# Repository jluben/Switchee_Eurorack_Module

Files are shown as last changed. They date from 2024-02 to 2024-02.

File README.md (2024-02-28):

# Switchee Eurorack Module
Switchee is a Eurorack signal switcher using the ATSAMD10D14A. It's a fairly simple design that uses the MCU to control DG447 analog signal switchers. The DG447 a cheap and can handle the full voltage bandwidth of typical Eurorack signals. Assemble is with SMD components, and the PCB falls into budget range of JLCPCB. When this was designed in 2022, you could build a unit for under $30. Even cheaper if you wanted to build ten units.

The default behavior is to advance the output from one to four for each trigger input. The mode button changes this behavior. There are three counting modes: linear, exponential (up to 1024), and fibonacci. In exponential mode, it takes an increase number of triggers to advance the counter and change the output. For example, 2, 4, 8, 16, etc. The fibonacci mode is similiar: it takes 1, 1, 2, 3, 5, 8 and so on triggers to change the output routing.

The module has:
* A TRIGGER input that changes the output
* A Signal input that is buffered and routed to one of four outputs
* A Reset input that changes the switching back to Output One
* A Mode button 

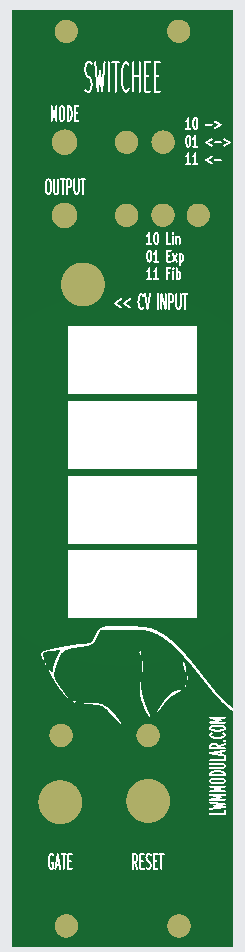
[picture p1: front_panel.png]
Front Panel Preview

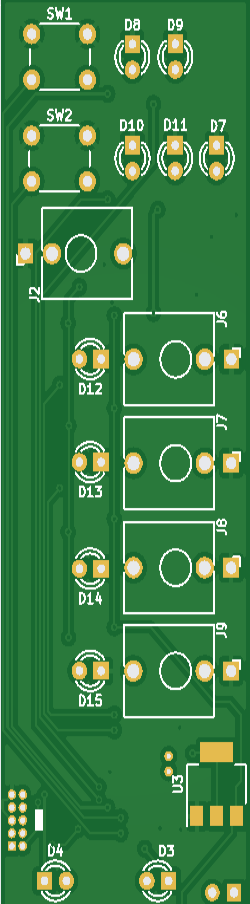
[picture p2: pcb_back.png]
PCB Back

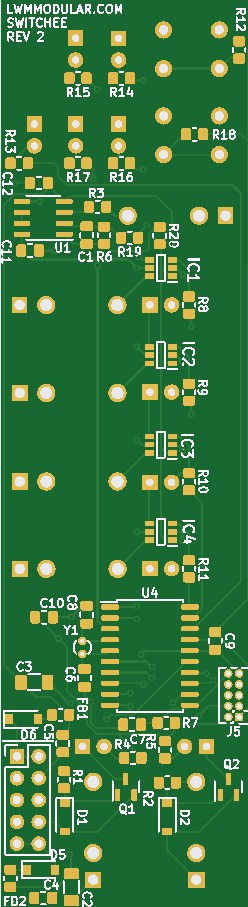
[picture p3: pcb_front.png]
PCB Front


This project includes the PCB, PCB front panel, and firmware. Firmware is downloaded to the ATSAMD10 via ATMEL ICE.

The PCB is done in Kicad. There are fab-ready gerbers in the gerbers/ directory. The main firmware file is in firmware/main.c

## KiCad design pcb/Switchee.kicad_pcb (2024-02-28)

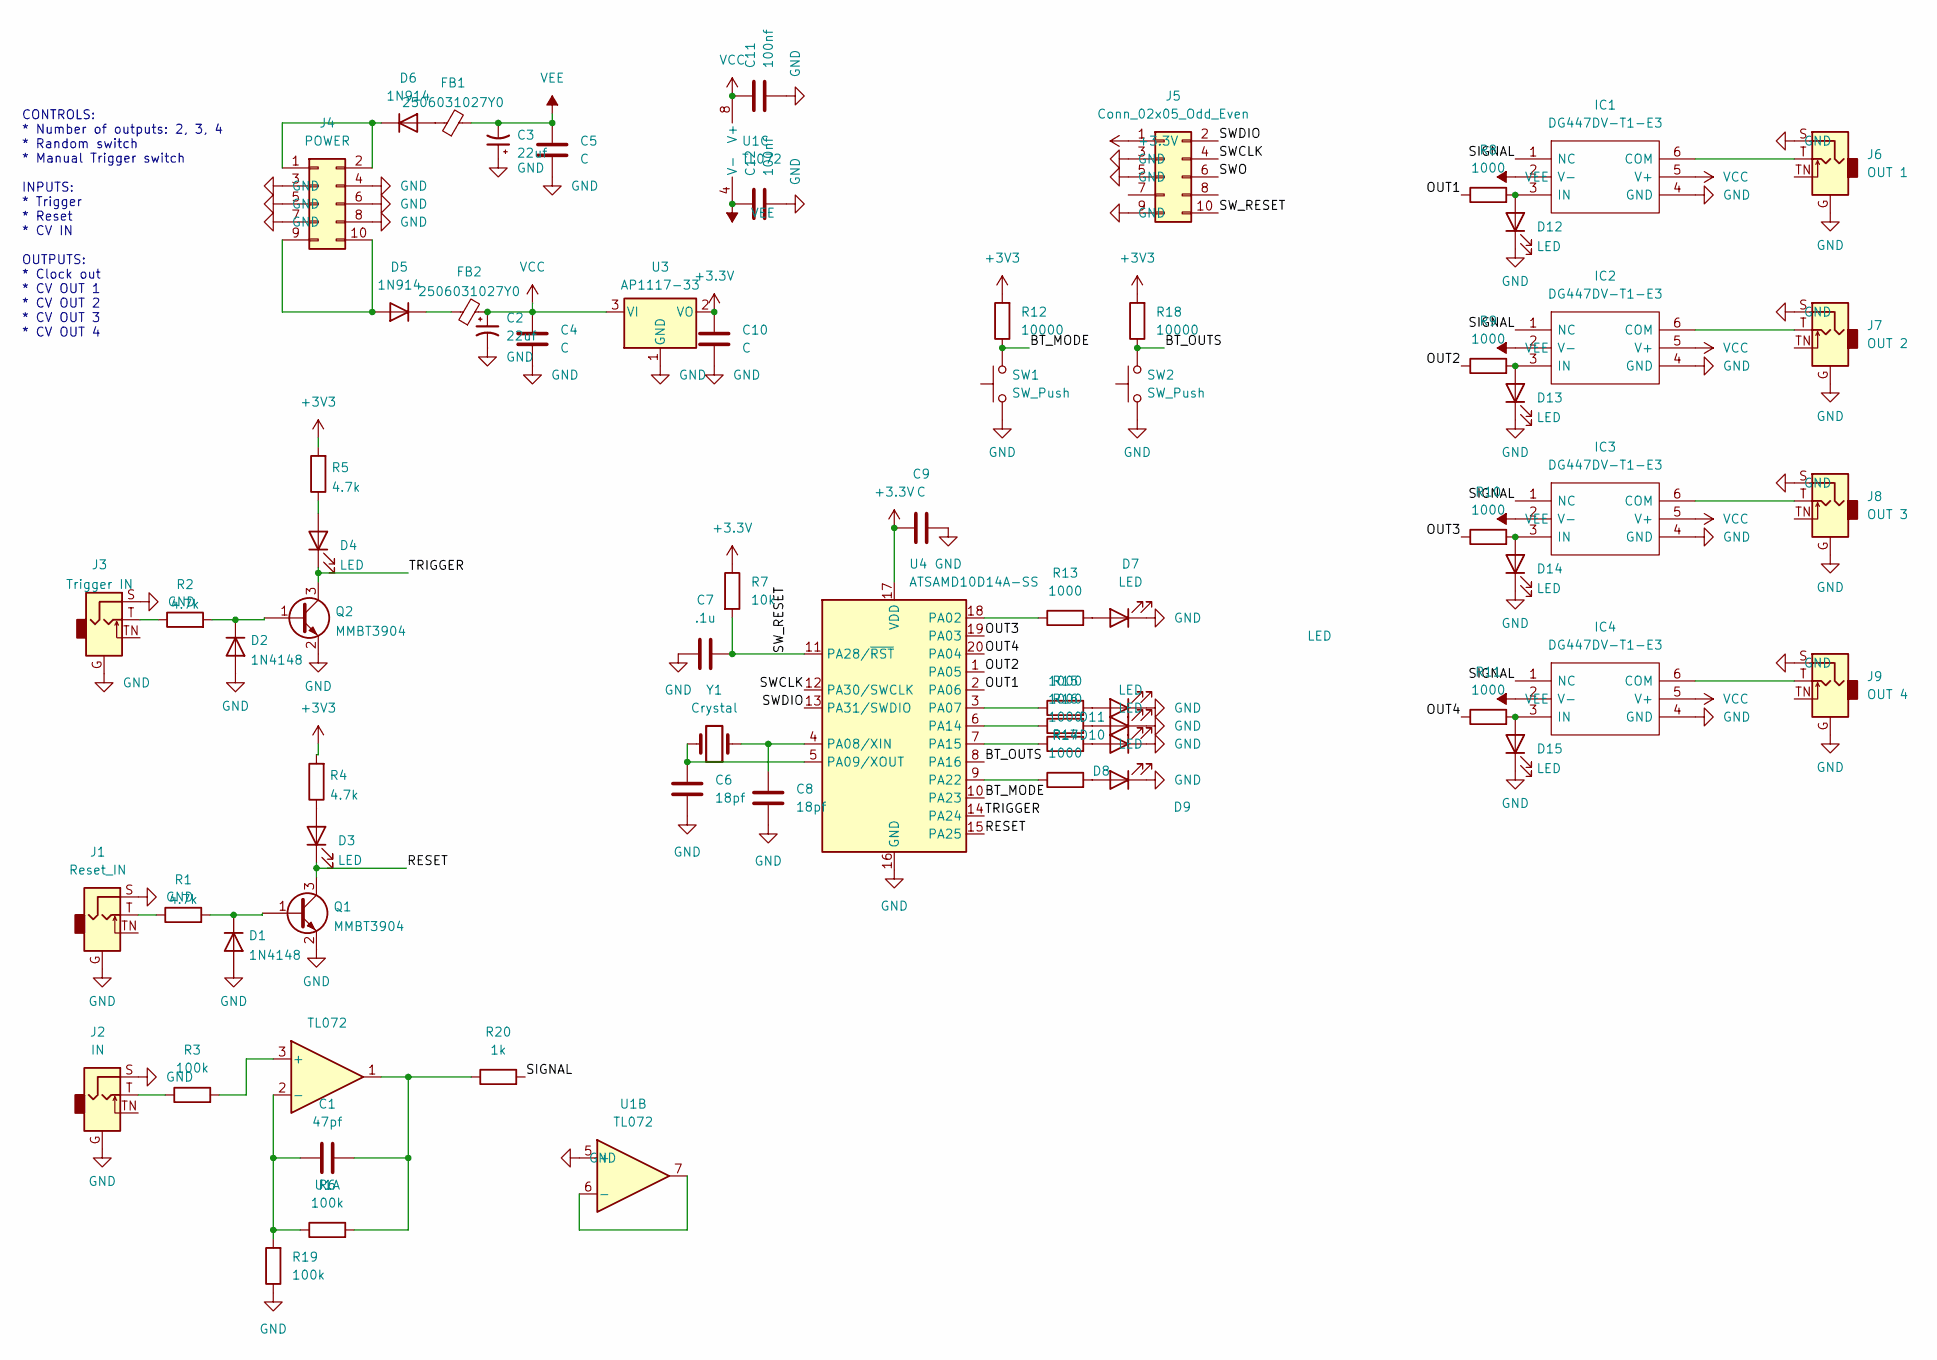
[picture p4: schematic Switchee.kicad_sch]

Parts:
C1: 47pf; C_0805_2012Metric_Pad1.18x1.45mm_HandSolder
C2, C3: 22uf; C_1206_3216Metric_Pad1.33x1.80mm_HandSolder
C4, C5, C9, C10: C; C_0805_2012Metric_Pad1.18x1.45mm_HandSolder
C6, C8: 18pf; C_0805_2012Metric_Pad1.18x1.45mm_HandSolder
C7: .1u; C_0805_2012Metric_Pad1.18x1.45mm_HandSolder
C11, C12: 100nf; C_0805_2012Metric_Pad1.18x1.45mm_HandSolder
D1, D2: 1N4148; D_SOD-123
D3, D4, D7, D8, D9, D10, D11, D12, D13, D14, D15: LED; LED_D3.0mm
D5, D6: 1N914; D_SOD-123
FB1, FB2: 2506031027Y0; R_0805_2012Metric_Pad1.20x1.40mm_HandSolder
IC1, IC2, IC3, IC4: DG447DV-T1-E3; SOP95P284X110-6N; Mouser Part Number 781-DG447DV-E3
J1: Reset_IN; Jack_3.5mm_QingPu_WQP-PJ398SM_Vertical_CircularHoles
J2: IN; Jack_3.5mm_QingPu_WQP-PJ398SM_Vertical_CircularHoles
J3: Trigger IN; Jack_3.5mm_QingPu_WQP-PJ398SM_Vertical_CircularHoles
J4: POWER; PinHeader_2x05_P2.54mm_Vertical
J5: Conn_02x05_Odd_Even; PinHeader_2x05_P1.27mm_Vertical
J6: OUT 1; Jack_3.5mm_QingPu_WQP-PJ398SM_Vertical_CircularHoles
J7: OUT 2; Jack_3.5mm_QingPu_WQP-PJ398SM_Vertical_CircularHoles
J8: OUT 3; Jack_3.5mm_QingPu_WQP-PJ398SM_Vertical_CircularHoles
J9: OUT 4; Jack_3.5mm_QingPu_WQP-PJ398SM_Vertical_CircularHoles
Q1, Q2: MMBT3904; SOT-23
R1, R2, R4, R5: 4.7k; R_0805_2012Metric_Pad1.20x1.40mm_HandSolder
R3, R6, R19: 100k; R_0805_2012Metric_Pad1.20x1.40mm_HandSolder
R7: 10k; R_0805_2012Metric_Pad1.20x1.40mm_HandSolder
R8, R9, R10, R11, R13, R14, R15, R16, R17: 1000; R_0805_2012Metric_Pad1.20x1.40mm_HandSolder
R12, R18: 10000; R_0805_2012Metric_Pad1.20x1.40mm_HandSolder
R20: 1k; R_0805_2012Metric_Pad1.20x1.40mm_HandSolder
SW1, SW2: SW_Push; SW_PUSH_6mm
U1: TL072; SOIC-8_3.9x4.9mm_P1.27mm
U3: AP1117-33; SOT-223-3_TabPin2
U4: ATSAMD10D14A-SS; SOIC-20W_7.5x12.8mm_P1.27mm
Y1: Crystal; Crystal_Round_D1.0mm_Vertical

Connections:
/BT_MODE: R12.1, SW1.2, U4.10 (PA23)
/BT_OUTS: R18.1, SW2.2, U4.8 (PA16)
/OUT1: R8.1, U4.2 (PA06)
/OUT2: R9.1, U4.1 (PA05)
/OUT3: R10.1, U4.19 (PA03)
/OUT4: R11.1, U4.20 (PA04)
/RESET: D3.1 (K), Q1.3 (C), U4.15 (PA25)
/SIGNAL: IC1.1 (NC), IC2.1 (NC), IC3.1 (NC), IC4.1 (NC), R20.2
/SWCLK: J5.4, U4.12 (PA30/SWCLK)
/SWDIO: J5.2, U4.13 (PA31/SWDIO)
/SWO: J5.6
/SW_RESET: C7.1, J5.10, R7.2, U4.11 (PA28/~RST)
/TRIGGER: D4.1 (K), Q2.3 (C), U4.14 (PA24)
GND: C2.2, C3.1, C4.2, C5.2, C6.2, C7.2, C8.2, C9.2, C10.2, C11.2, C12.2, D1.2 (A), D2.2 (A), D7.1 (K), D8.1 (K), D9.1 (K), D10.1 (K), D11.1 (K), D12.1 (K), D13.1 (K), D14.1 (K), D15.1 (K), IC1.4 (GND), IC2.4 (GND), IC3.4 (GND), IC4.4 (GND), J1.G, J1.S, J2.G, J2.S, J3.G, J3.S, J4.3, J4.4, J4.5, J4.6, J4.7, J4.8, J5.3, J5.5, J5.9, J6.G, J6.S, J7.G, J7.S, J8.G, J8.S, J9.G, J9.S, Q1.2 (E), Q2.2 (E), R19.1, SW1.1, SW2.1, U1.5 (+), U3.1 (GND), U4.16 (GND)
unnamed: C1.2, R6.2, R20.1, U1.1
unnamed: C6.1, U4.5 (PA09/XOUT), Y1.2
unnamed: C8.1, U4.4 (PA08/XIN), Y1.1
unnamed: D1.1 (K), Q1.1 (B), R1.2
unnamed: D2.1 (K), Q2.1 (B), R2.2
unnamed: D3.2 (A), R4.1
unnamed: D4.2 (A), R5.1
unnamed: D5.1 (K), FB2.1
unnamed: D5.2 (A), J4.9, J4.10
unnamed: D6.1 (K), J4.1, J4.2
unnamed: D6.2 (A), FB1.1
unnamed: D7.2 (A), R13.2
unnamed: D8.2 (A), R14.2
unnamed: D9.2 (A), R15.2
unnamed: D10.2 (A), R16.2
unnamed: D11.2 (A), R17.2
unnamed: D12.2 (A), IC1.3 (IN), R8.2
unnamed: D13.2 (A), IC2.3 (IN), R9.2
unnamed: D14.2 (A), IC3.3 (IN), R10.2
unnamed: D15.2 (A), IC4.3 (IN), R11.2
unnamed: IC1.6 (COM), J6.T
unnamed: IC2.6 (COM), J7.T
unnamed: IC3.6 (COM), J8.T
unnamed: IC4.6 (COM), J9.T
unnamed: J1.T, R1.1
unnamed: J2.T, R3.1
unnamed: J3.T, R2.1
unnamed: R3.2, U1.3 (+)
unnamed: R13.1, U4.18 (PA02)
unnamed: R14.1, U4.9 (PA22)
unnamed: R15.1, U4.6 (PA14)
unnamed: R16.1, U4.7 (PA15)
unnamed: R17.1, U4.3 (PA07)
unnamed: C1.1, R6.1, R19.2, U1.2 (-)
unnamed: U1.6 (-), U1.7
VCC: C2.1, C4.1, C11.1, FB2.2, IC1.5 (V+), IC2.5 (V+), IC3.5 (V+), IC4.5 (V+), U1.8 (V+), U3.3 (VI)
VEE: C3.2, C5.1, C12.1, FB1.2, IC1.2 (V-), IC2.2 (V-), IC3.2 (V-), IC4.2 (V-), U1.4 (V-)

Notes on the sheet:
CONTROLS: * Number of outputs: 2, 3, 4 * Random switch * Manual Trigger switch INPUTS: * Trigger * Reset * CV IN OUTPUTS: * Clock out * CV OUT 1 * CV OUT 2 * CV OUT 3 * CV OUT 4

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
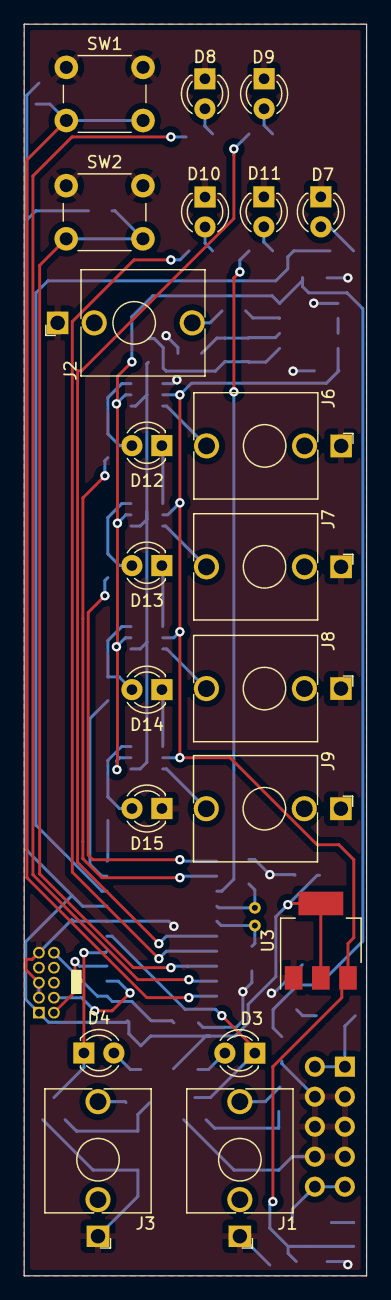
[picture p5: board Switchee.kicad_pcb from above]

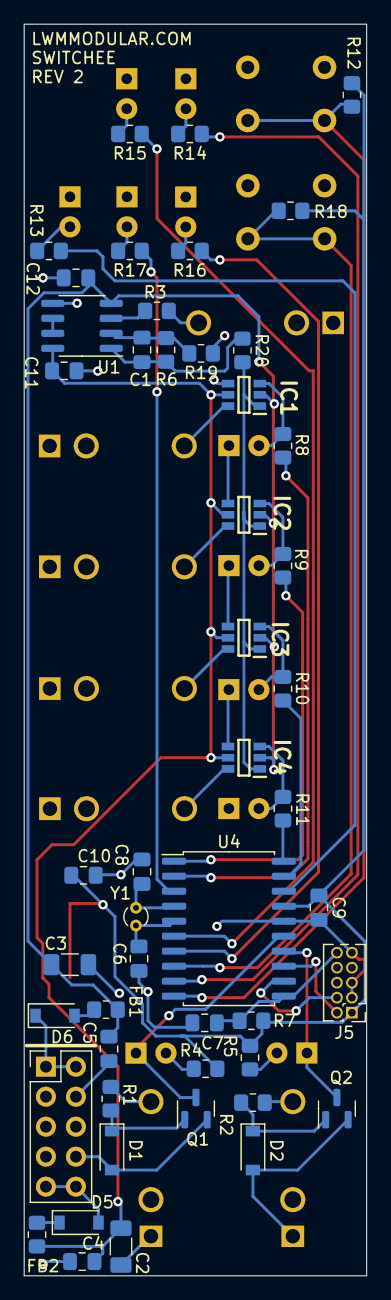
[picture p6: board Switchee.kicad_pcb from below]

Board: 2 copper layers, 29.0 x 106.0 mm, 70 parts (49 on the bottom side), 51 nets.

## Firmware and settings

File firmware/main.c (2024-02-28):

/**
 * This is the firmware for the Switchee Eurorack module. It is designed around a ATSAMD10. The 
 * MCU looks for trigger and reset inputs, and then decides how to change the output routing of 
 * the four analog signal switchers (DG447). A lot of this code is management of the hardware
 * user interface. The mode is saved to flash after a long enough delay to not exceed the flash
 * lifetime.
*/
#include <atmel_start.h>

enum 
{
	kModeSequential=0,
	kModeBounce=1,
	kModeInverted=2,
	
	kModeLast
};

enum
{
	kCounterModeLinear=0,
	kCounterModeExponential,
	kCounterModeFibonacci,
	
	kCounterModeLast
};

typedef enum
{
	kForwards,
	kBackwards
	
} BounceDirection;
	
const int kLongHoldTicks = 20000;
const int kSaveSettingsDelay = 500000;
const int kDebounceTicks = 1000;
const int kDebounceSignalTicks = 1000;
#define kExponentialSize  10
const int32_t kExponential[kExponentialSize] = {2, 4, 8, 16, 32, 64, 128, 256, 512, 1024};
#define kFibonacciSize  18
const int32_t kFibonacci[kFibonacciSize] = {0, 1, 1, 2, 3, 5, 8, 13, 21, 34, 55, 89, 144, 233, 377, 610, 987, 1597};

volatile int64_t gTicks=0;
volatile int8_t gChannel1=false;
volatile int8_t gChannel2=false;
volatile int8_t gChannel3=false;
volatile int8_t gChannel4=false;
volatile int8_t gLinearChannelIndex=0;
volatile BounceDirection gBounceDirection=kForwards;
volatile bool gSettingsDirty=false;
volatile bool gInvertChannels=false;
volatile int32_t gCounter=0;


volatile int8_t gSwitcheeMode=kModeSequential;
volatile int8_t gCounterMode=kCounterModeLinear;

static void TIMER_0_task1_cb(const struct timer_task *const timer_task)
{
	++gTicks;
}

static struct timer_task TIMER_0_task1;
void setupTimer(void)
{
	TIMER_0_task1.interval = 2;
	TIMER_0_task1.cb       = TIMER_0_task1_cb;
	TIMER_0_task1.mode     = TIMER_TASK_REPEAT;

	timer_add_task(&TIMER_0, &TIMER_0_task1);
	timer_start(&TIMER_0);
}


void setCounterModeIndicators()
{
	bool D10=false;
	bool D11=false;
	
	switch (gCounterMode)
	{
		case kCounterModeLinear:
			D10 = true;
			break;
		case kCounterModeExponential:
			D11 = true;
			break;
		case kModeInverted:
			D10 = true;
			D11 = true;
			break;
	}
	
	gpio_set_pin_level(LED10, D10);
	gpio_set_pin_level(LED11, D11);
}


void incrementCounterMode()
{
	gCounterMode = (1+gCounterMode) % kCounterModeLast;
	setCounterModeIndicators();
	
	gSettingsDirty = true;
	gCounter = 0;
}

void checkCounterModeButton()
{
	static volatile bool sLastCounterMode=false;
	static volatile int64_t sLastCounterModeTicks=0;
	
	bool input = !gpio_get_pin_level(SW_OUT);
	
	if (input != sLastCounterMode)
	{
		if ((gTicks-sLastCounterModeTicks) > kDebounceTicks)
		{
			if (input)
			{
				incrementCounterMode();
			}
			
			sLastCounterModeTicks = gTicks;
		}
		sLastCounterMode = input;
	}
}

void incrementMode()
{
	gSwitcheeMode = (1+gSwitcheeMode) % kModeLast;
	gInvertChannels = (gSwitcheeMode == kModeInverted);
	setModeIndicators();
	
	gSettingsDirty = true;
	gLinearChannelIndex = 0;
	gCounter = 0;
	clearChannels();
}

void setModeIndicators()
{
	bool D8=false;
	bool D9=false;
	
	switch (gSwitcheeMode)
	{
		case kModeSequential:
			D8 = true;
			break;
		case kModeBounce:
			D9 = true;
			break;
		case kCounterModeFibonacci:
			D8 = true;
			D9 = true;
			break;
	}
	
	gpio_set_pin_level(LED8, D8);
	gpio_set_pin_level(LED9, D9);
}

void flashModeIndicators()
{
	gpio_set_pin_level(LED8, true);
	gpio_set_pin_level(LED9, true);	
	delay_ms(100);
	gpio_set_pin_level(LED8, false);
	gpio_set_pin_level(LED9, false);
	delay_ms(100);
	gpio_set_pin_level(LED8, true);
	gpio_set_pin_level(LED9, true);
	delay_ms(100);
	
	setModeIndicators();	// Restore the proper state
}

void flashCounterModeIndicators()
{
	gpio_set_pin_level(LED10, true);
	gpio_set_pin_level(LED11, true);
	delay_ms(100);
	gpio_set_pin_level(LED10, false);
	gpio_set_pin_level(LED11, false);
	delay_ms(100);
	gpio_set_pin_level(LED10, true);
	gpio_set_pin_level(LED11, true);
	delay_ms(100);
	
	setCounterModeIndicators();	// Restore the proper state
}



void checkModeButton()
{
	static volatile bool sLastSWModePress=false;
	static volatile int64_t sLastSWModePressTicks=0;
	static volatile int64_t sLastSWModeLongholdTicks=0;
	
	bool swModePress = !gpio_get_pin_level(SW_MODE);
	
	if (swModePress != sLastSWModePress)
	{
		if ((gTicks-sLastSWModePressTicks) > kDebounceTicks)
		{
			if (!swModePress)	// Do this on button release
			{
				if ((gTicks-sLastSWModeLongholdTicks) > kLongHoldTicks)
				{
					flashModeIndicators();
					reset();
				}
				else
				{
					incrementMode();
				}
				sLastSWModeLongholdTicks = 0;
			}
			else
			{
				sLastSWModeLongholdTicks = gTicks;
			}
		
			sLastSWModePressTicks = gTicks;
		}
		sLastSWModePress = swModePress;
	}
}

void clearChannels()
{
	gChannel1 = gChannel2 = gChannel3 = gChannel4 = false;
	setChannels();
}

void setChannels()
{
	gpio_set_pin_level(OUT1, gInvertChannels ? !gChannel1 : gChannel1);
	gpio_set_pin_level(OUT2, gInvertChannels ? !gChannel2 : gChannel2);
	gpio_set_pin_level(OUT3, gInvertChannels ? !gChannel3 : gChannel3);
	gpio_set_pin_level(OUT4, gInvertChannels ? !gChannel4 : gChannel4);
}

void increment()
{
	++gCounter;
	
	switch (gCounterMode)
	{
		case kCounterModeLinear:
			gLinearChannelIndex = (1+gLinearChannelIndex) % 5;
			break;
		case kCounterModeExponential:
			for (auto i=0 ; i < kExponentialSize ; ++i)
			{
				if (gCounter == kExponential[i])
				{
					gLinearChannelIndex = (1+gLinearChannelIndex) % 5;
					
					if (i == kExponentialSize-1)
					{
						gCounter=0;
					}
					break;
				}
			}
			break;
		case kCounterModeFibonacci:
			for (auto i=0 ; i < kFibonacciSize ; ++i)
			{
				if (gCounter == kFibonacci[i])
				{
					gLinearChannelIndex = (1+gLinearChannelIndex) % 5;
					return;
				}
			}
			
			gCounter=0;
			break;
	}
}


void decrement()
{
	--gCounter;
	
	switch (gCounterMode)
	{
		case kCounterModeLinear:
			--gLinearChannelIndex;
			break;
		case kCounterModeExponential:
			for (auto i=0 ; i < kExponentialSize ; ++i)
			{
				if (gCounter == kExponential[i])
				{
					--gLinearChannelIndex;
					if (i == kExponentialSize-1)
					{
						gCounter=0;
					}
					break;
				}
			}
			break;
		case kCounterModeFibonacci:
			for (auto i=0 ; i < kFibonacciSize ; ++i)
			{
				if (gCounter == kFibonacci[i])
				{
					--gLinearChannelIndex;
					return;
				}
			}
		
			gCounter=0;
			break;
	}
}


void incrementLinear()
{
	increment();
	
	
	gChannel1 = gChannel2 = gChannel3 = gChannel4 = false;
	
	switch (gLinearChannelIndex)
	{
		case 0:
			// All are turned off.
			break;
		case 1:
			gChannel1 = true;
			break;
		case 2:
			gChannel2 = true;
			break;
		case 3:
			gChannel3 = true;
			break;
		case 4:
			gChannel4 = true;
			break;
	}
}

void incrementBounce()
{
	if (kForwards == gBounceDirection && gLinearChannelIndex==4)
		gBounceDirection = kBackwards;
	else if (kBackwards == gBounceDirection && gLinearChannelIndex==0)
		gBounceDirection = kForwards;
	
	if (kForwards == gBounceDirection)
	{
		increment();
	}
	else if (kBackwards == gBounceDirection)
	{
		decrement();
	}
	
	
	gChannel1 = gChannel2 = gChannel3 = gChannel4 = false;
	
	switch (gLinearChannelIndex)
	{
		case 0:
		// All are turned off.
		break;
		case 1:
		gChannel1 = true;
		break;
		case 2:
		gChannel2 = true;
		break;
		case 3:
		gChannel3 = true;
		break;
		case 4:
		gChannel4 = true;
		break;
	}
}

void trigger()
{
	switch (gSwitcheeMode)
	{
		case kModeSequential:
		case kModeInverted:
			incrementLinear();
			break;
		case kModeBounce:
			incrementBounce();
			break;
	}
	
	setChannels();
}


void reset()
{
	gBounceDirection = kForwards;
	gLinearChannelIndex = 0;
	gChannel1 = gChannel2 = gChannel3 = gChannel4 = false;
	gCounter = 0;
	
	setChannels();
}

void checkTrigger()
{
	static volatile bool sLastTrigger=false;
	static volatile int64_t sLastTriggerTicks=0;
	
	bool input = !gpio_get_pin_level(IN_TRIGGER);
	
	if (input != sLastTrigger)
	{
		if ((gTicks-sLastTriggerTicks) > kDebounceSignalTicks)
		{
			if (input)
			{
				trigger();
			}
			
			sLastTriggerTicks = gTicks;
		}
		sLastTrigger = input;
	}
}



void checkReset()
{
	static volatile bool sLastReset=false;
	static volatile int64_t sLastResetTicks=0;
	
	
	bool input = !gpio_get_pin_level(IN_RESET);
	
	if (input != sLastReset)
	{
		if ((gTicks-sLastResetTicks) > kDebounceSignalTicks)
		{
			if (input)
			{
				reset();
			}
			
			sLastResetTicks = gTicks;
		}
		sLastReset = input;
	}
}

void saveSettings()
{
	static volatile int64_t sLastSaveTicks=0;

	if ((gTicks - sLastSaveTicks) > kSaveSettingsDelay)
	{
		// page size 3 is 64 bytes.
		//volatile uint8_t page_size = NVMCTRL->PARAM.bit.PSZ;
		
		uint8_t page_data[64];
		
		flash_read(&FLASH_0, 0x3200, page_data, 64);
		
		page_data[0] = gSwitcheeMode;
		page_data[1] = gCounterMode;
		
		flash_write(&FLASH_0, 0x3200, page_data, 64);
		
		sLastSaveTicks = gTicks;
	}
}

void readSettings()
{
	uint8_t page_data[64];
	flash_read(&FLASH_0, 0x3200, page_data, 64);
	
	gSwitcheeMode = page_data[0];
	if (gSwitcheeMode != kModeSequential && gSwitcheeMode != kModeBounce && gSwitcheeMode != kModeInverted)
		gSwitcheeMode = kModeSequential;
		
	gInvertChannels = (gSwitcheeMode == kModeInverted);
	
	gCounterMode = page_data[1];
	if (gCounterMode != kCounterModeLinear && gCounterMode != kCounterModeExponential && gCounterMode != kCounterModeFibonacci)
		gCounterMode = kCounterModeLinear;
}


int main(void)
{
	atmel_start_init();

	dac_sync_enable_channel(&DAC_0, 0);

	setupTimer();
	
	readSettings();
	
	flashModeIndicators();
	flashCounterModeIndicators();
	
	setModeIndicators();
	setCounterModeIndicators();

	while (1)
	{
		checkModeButton();
		checkCounterModeButton();
		checkTrigger();
		checkReset();
		
		if (gSettingsDirty)
		{
			saveSettings();	
		}
	}
}

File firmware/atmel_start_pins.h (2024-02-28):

/*
 * Code generated from Atmel Start.
 *
 * This file will be overwritten when reconfiguring your Atmel Start project.
 * Please copy examples or other code you want to keep to a separate file
 * to avoid losing it when reconfiguring.
 */
#ifndef ATMEL_START_PINS_H_INCLUDED
#define ATMEL_START_PINS_H_INCLUDED

#include <hal_gpio.h>

// SAMD10 has 8 pin functions

#define GPIO_PIN_FUNCTION_A 0
#define GPIO_PIN_FUNCTION_B 1
#define GPIO_PIN_FUNCTION_C 2
#define GPIO_PIN_FUNCTION_D 3
#define GPIO_PIN_FUNCTION_E 4
#define GPIO_PIN_FUNCTION_F 5
#define GPIO_PIN_FUNCTION_G 6
#define GPIO_PIN_FUNCTION_H 7

#define LED7 GPIO(GPIO_PORTA, 2)
#define OUT3 GPIO(GPIO_PORTA, 3)
#define OUT4 GPIO(GPIO_PORTA, 4)
#define OUT2 GPIO(GPIO_PORTA, 5)
#define OUT1 GPIO(GPIO_PORTA, 6)
#define LED11 GPIO(GPIO_PORTA, 7)
#define LED9 GPIO(GPIO_PORTA, 14)
#define LED10 GPIO(GPIO_PORTA, 15)
#define SW_OUT GPIO(GPIO_PORTA, 16)
#define LED8 GPIO(GPIO_PORTA, 22)
#define SW_MODE GPIO(GPIO_PORTA, 23)
#define IN_TRIGGER GPIO(GPIO_PORTA, 24)
#define IN_RESET GPIO(GPIO_PORTA, 25)

#endif // ATMEL_START_PINS_H_INCLUDED

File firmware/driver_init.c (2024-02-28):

/*
 * Code generated from Atmel Start.
 *
 * This file will be overwritten when reconfiguring your Atmel Start project.
 * Please copy examples or other code you want to keep to a separate file
 * to avoid losing it when reconfiguring.
 */

#include "driver_init.h"
#include <peripheral_clk_config.h>
#include <utils.h>
#include <hal_init.h>
#include <hpl_gclk_base.h>
#include <hpl_pm_base.h>

#include <hpl_rtc_base.h>

struct timer_descriptor TIMER_0;

struct flash_descriptor FLASH_0;

struct dac_sync_descriptor DAC_0;

void FLASH_0_CLOCK_init(void)
{

	_pm_enable_bus_clock(PM_BUS_APBB, NVMCTRL);
}

void FLASH_0_init(void)
{
	FLASH_0_CLOCK_init();
	flash_init(&FLASH_0, NVMCTRL);
}

void delay_driver_init(void)
{
	delay_init(SysTick);
}

/**
 * \brief Timer initialization function
 *
 * Enables Timer peripheral, clocks and initializes Timer driver
 */
static void TIMER_0_init(void)
{
	_pm_enable_bus_clock(PM_BUS_APBA, RTC);
	_gclk_enable_channel(RTC_GCLK_ID, CONF_GCLK_RTC_SRC);
	timer_init(&TIMER_0, RTC, _rtc_get_timer());
}

void DAC_0_PORT_init(void)
{
}

void DAC_0_CLOCK_init(void)
{

	_pm_enable_bus_clock(PM_BUS_APBC, DAC);
	_gclk_enable_channel(DAC_GCLK_ID, CONF_GCLK_DAC_SRC);
}

void DAC_0_init(void)
{
	DAC_0_CLOCK_init();
	dac_sync_init(&DAC_0, DAC);
	DAC_0_PORT_init();
}

void system_init(void)
{
	init_mcu();

	// GPIO on PA02

	// Disable digital pin circuitry
	gpio_set_pin_direction(LED7, GPIO_DIRECTION_OFF);

	gpio_set_pin_function(LED7, GPIO_PIN_FUNCTION_OFF);

	// GPIO on PA03

	gpio_set_pin_level(OUT3,
	                   // <y> Initial level
	                   // <id> pad_initial_level
	                   // <false"> Low
	                   // <true"> High
	                   false);

	// Set pin direction to output
	gpio_set_pin_direction(OUT3, GPIO_DIRECTION_OUT);

	gpio_set_pin_function(OUT3, GPIO_PIN_FUNCTION_OFF);

	// GPIO on PA04

	gpio_set_pin_level(OUT4,
	                   // <y> Initial level
	                   // <id> pad_initial_level
	                   // <false"> Low
	                   // <true"> High
	                   false);

	// Set pin direction to output
	gpio_set_pin_direction(OUT4, GPIO_DIRECTION_OUT);

	gpio_set_pin_function(OUT4, GPIO_PIN_FUNCTION_OFF);

	// GPIO on PA05

	gpio_set_pin_level(OUT2,
	                   // <y> Initial level
	                   // <id> pad_initial_level
	                   // <false"> Low
	                   // <true"> High
	                   false);

	// Set pin direction to output
	gpio_set_pin_direction(OUT2, GPIO_DIRECTION_OUT);

	gpio_set_pin_function(OUT2, GPIO_PIN_FUNCTION_OFF);

	// GPIO on PA06

	gpio_set_pin_level(OUT1,
	                   // <y> Initial level
	                   // <id> pad_initial_level
	                   // <false"> Low
	                   // <true"> High
	                   false);

	// Set pin direction to output
	gpio_set_pin_direction(OUT1, GPIO_DIRECTION_OUT);

	gpio_set_pin_function(OUT1, GPIO_PIN_FUNCTION_OFF);

	// GPIO on PA07

	gpio_set_pin_level(LED11,
	                   // <y> Initial level
	                   // <id> pad_initial_level
	                   // <false"> Low
	                   // <true"> High
	                   false);

	// Set pin direction to output
	gpio_set_pin_direction(LED11, GPIO_DIRECTION_OUT);

	gpio_set_pin_function(LED11, GPIO_PIN_FUNCTION_OFF);

	// GPIO on PA14

	gpio_set_pin_level(LED9,
	                   // <y> Initial level
	                   // <id> pad_initial_level
	                   // <false"> Low
	                   // <true"> High
	                   false);

	// Set pin direction to output
	gpio_set_pin_direction(LED9, GPIO_DIRECTION_OUT);

	gpio_set_pin_function(LED9, GPIO_PIN_FUNCTION_OFF);

	// GPIO on PA15

	gpio_set_pin_level(LED10,
	                   // <y> Initial level
	                   // <id> pad_initial_level
	                   // <false"> Low
	                   // <true"> High
	                   false);

	// Set pin direction to output
	gpio_set_pin_direction(LED10, GPIO_DIRECTION_OUT);

	gpio_set_pin_function(LED10, GPIO_PIN_FUNCTION_OFF);

	// GPIO on PA16

	// Set pin direction to input
	gpio_set_pin_direction(SW_OUT, GPIO_DIRECTION_IN);

	gpio_set_pin_pull_mode(SW_OUT,
	                       // <y> Pull configuration
	                       // <id> pad_pull_config
	                       // <GPIO_PULL_OFF"> Off
	                       // <GPIO_PULL_UP"> Pull-up
	                       // <GPIO_PULL_DOWN"> Pull-down
	                       GPIO_PULL_OFF);

	gpio_set_pin_function(SW_OUT, GPIO_PIN_FUNCTION_OFF);

	// GPIO on PA22

	gpio_set_pin_level(LED8,
	                   // <y> Initial level
	                   // <id> pad_initial_level
	                   // <false"> Low
	                   // <true"> High
	                   false);

	// Set pin direction to output
	gpio_set_pin_direction(LED8, GPIO_DIRECTION_OUT);

	gpio_set_pin_function(LED8, GPIO_PIN_FUNCTION_OFF);

	// GPIO on PA23

	// Set pin direction to input
	gpio_set_pin_direction(SW_MODE, GPIO_DIRECTION_IN);

	gpio_set_pin_pull_mode(SW_MODE,
	                       // <y> Pull configuration
	                       // <id> pad_pull_config
	                       // <GPIO_PULL_OFF"> Off
	                       // <GPIO_PULL_UP"> Pull-up
	                       // <GPIO_PULL_DOWN"> Pull-down
	                       GPIO_PULL_OFF);

	gpio_set_pin_function(SW_MODE, GPIO_PIN_FUNCTION_OFF);

	// GPIO on PA24

	// Set pin direction to input
	gpio_set_pin_direction(IN_TRIGGER, GPIO_DIRECTION_IN);

	gpio_set_pin_pull_mode(IN_TRIGGER,
	                       // <y> Pull configuration
	                       // <id> pad_pull_config
	                       // <GPIO_PULL_OFF"> Off
	                       // <GPIO_PULL_UP"> Pull-up
	                       // <GPIO_PULL_DOWN"> Pull-down
	                       GPIO_PULL_OFF);

	gpio_set_pin_function(IN_TRIGGER, GPIO_PIN_FUNCTION_OFF);

	// GPIO on PA25

	// Set pin direction to input
	gpio_set_pin_direction(IN_RESET, GPIO_DIRECTION_IN);

	gpio_set_pin_pull_mode(IN_RESET,
	                       // <y> Pull configuration
	                       // <id> pad_pull_config
	                       // <GPIO_PULL_OFF"> Off
	                       // <GPIO_PULL_UP"> Pull-up
	                       // <GPIO_PULL_DOWN"> Pull-down
	                       GPIO_PULL_OFF);

	gpio_set_pin_function(IN_RESET, GPIO_PIN_FUNCTION_OFF);

	FLASH_0_init();

	delay_driver_init();

	TIMER_0_init();

	DAC_0_init();
}
